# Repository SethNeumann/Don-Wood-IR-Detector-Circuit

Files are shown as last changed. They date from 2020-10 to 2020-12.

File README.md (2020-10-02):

# REPO NAME: MRCS-Don-Wood-IR-Detector-Circuit

## License: Creative Commons Attribution-NonCommercial-ShareAlike

Don Wood offerd this circuit for an optical detector based on an IR emmitter/detector pair and
it used a segment of Dr. Chubb's SMC-12 as a substrate.  This is the same circuit without the
extraneous bits and and with dedicated pads for the pot and for a limiting resistor for the
emitter.  Terminal names stay close to the originals.  This ***may*** be a cost effective or
easier option for those needing a small number of detectors.  It will work as an ambient light
detector without an emitter but you are responsible for controlling ambient light and ensuring
illumination is consistent.

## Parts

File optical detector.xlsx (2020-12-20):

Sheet: Master BOM
Qty | Value | Device | Package | Parts | Description | Vendor | V-Part | Unit | Extd | EOQ
2 | 2 | CONNECTOR-M021X02-LOCK | 1X02_LOCK | J3, J4 | PHOENIX CONNECTOR | Asian |  | 0.25
1 | 6 | CONNECTOR-M06LOCK | 1X06_LOCK | J2 | Header 6 Standard 6-pin 0.1 header" | Asian |  | 0.50
1 | 8 | CONNECTOR-M08LOCK | 1X08_LOCK | J1 | Header 8 | Asian |  | 0.70
4 | 0 | RPTH-R0 | CUT-R | R7, R9, R10, R11 | Resistor
2 | 10K | TRIM_US-RS3 | RS3 | R2, R5 | POTENTIOMETER | Banggood |  | 0.07
1 | 1N5819 | DIODEPTH | DIODE-1N4001 | D1 | Diode | Jameco |  | 0.06
2 | 4700 | RPTH04 | AXIAL-0.4-RES | R3,R4 | Resistor | Jameco |  | 0.04
4 | 470 | RPTH04 | AXIAL-0.4-RES | R1, R6, R8, R12 | Resistor | Jameco |  | 0.04
1 | DC PWR | CONNECTOR-DC-POWER-RA | DCJ0202 | CON1 | DC POWER JACK | Asian |  | 0.10
1 | LM324N | LM324N | DIL14 | U1 | OP AMP | Jameco |  | 0.25
2 | RED | LED3MM | LED3MM | LED1, LED2 |  | Asian |  | 0.01
1 |  | PCB |  |  | MRCS-Don-Woods-IR-Detector | MRCS |  | 1.67
1 | labor | pin |  |  |  |  |  | 0.20
 | Markup | 20%
 | ecommerce | 10%

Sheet: Minimal-Single
Qty | Value | Device | Package | Parts | Description | Vendor | V-Part | Unit | Extd | EOQ | leads | leads extd
 | 2 | CONNECTOR-M021X02-LOCK | 1X02_LOCK | J3, J4 | PHOENIX CONNECTOR | Asian | 0 | 0.25 | 0.00 | 100 | 2 | 0
1 | 6 | CONNECTOR-M06LOCK | 1X06_LOCK | J2 | Header 6 Standard 6-pin 0.1 header" | Asian | 0 | 0.50 | 0.50 | 100 | 6 | 6
 | 8 | CONNECTOR-M08LOCK | 1X08_LOCK | J1 | Header 8 | Asian | 0 | 0.70 | 0.00 | 100 | 8 | 0
 | 0 | RPTH-R0 | CUT-R | R7, R9, R10, R11 | Resistor |  | 0 | 0.00 | 0.00 | 100 | 2 | 0
1 | 10K | TRIM_US-RS3 | RS3 | R2, R5 | POTENTIOMETER | Banggood | 0 | 0.07 | 0.07 | 100 | 3 | 3
1 | 1N5819 | DIODEPTH | DIODE-1N4001 | D1 | Diode | Jameco | 0 | 0.06 | 0.06 | 100 | 2 | 2
1 | 4700 | RPTH04 | AXIAL-0.4-RES | R3,R4 | Resistor | Jameco | 0 | 0.04 | 0.04 | 100 | 2 | 2
 | 470 | RPTH04 | AXIAL-0.4-RES | R1, R6, R8, R12 | Resistor | Jameco | 0 | 0.04 | 0.00 | 100 | 2 | 0
 | DC PWR | CONNECTOR-DC-POWER-RA | DCJ0202 | CON1 | DC POWER JACK | Asian | 0 | 0.10 | 0.00 | 100 | 3 | 0
1 | LM324N | LM324N | DIL14 | U1 | OP AMP | Jameco | 0 | 0.25 | 0.25 | 100 |  | 0
1 | DIL14 | Socket DIL14 | LED3MM | U1S | 14 oin dip socket | Jameco |  | 0.20 | 0.20 | 100 | 14 | 14
1 | 0 | PCB | 0 | 0 | MRCS-Don-Woods-IR-Detector | MRCS | 0 | 1.67 | 1.67 | 100
 |  | Parts total |  |  |  |  |  |  | 2.79 |  |  | 27
27 |  | Labor |  |  |  |  |  | 0.20 | 5.40
 |  | Cost subtotal |  |  |  |  |  |  | 8.19
 |  | Markup |  |  |  |  |  |  | 1.64
 |  | marked up subtotal |  |  |  |  |  |  | 9.83
 |  | E-commerce |  |  |  |  |  |  | 0.98
 |  | Grand Total |  |  |  |  |  |  | 10.81
 |  | Sell |  |  |  |  |  |  | $11.00

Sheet: Dual with Emitters
Qty | Value | Device | Package | Parts | Description | Vendor | V-Part | Unit | Extd | EOQ | leads | leads extd
 | 2 | CONNECTOR-M021X02-LOCK | 1X02_LOCK | J3, J4 | PHOENIX CONNECTOR | Asian | 0 | 0.25 | 0.00 | 100 | 2 | 0
1 | 6 | CONNECTOR-M06LOCK | 1X06_LOCK | J2 | Header 6 Standard 6-pin 0.1 header" | Asian | 0 | 0.50 | 0.50 | 100 | 6 | 6
1 | 8 | CONNECTOR-M08LOCK | 1X08_LOCK | J1 | Header 8 | Asian | 0 | 0.70 | 0.70 | 100 | 8 | 8
 | 0 | RPTH-R0 | CUT-R | R7, R9, R10, R11 | Resistor |  | 0 | 0.00 | 0.00 | 100 | 2 | 0
2 | 10K | TRIM_US-RS3 | RS3 | R2, R5 | POTENTIOMETER | Banggood | 0 | 0.07 | 0.14 | 100 | 3 | 6
1 | 1N5819 | DIODEPTH | DIODE-1N4001 | D1 | Diode | Jameco | 0 | 0.06 | 0.06 | 100 | 2 | 2
2 | 4700 | RPTH04 | AXIAL-0.4-RES | R3,R4 | Resistor | Jameco | 0 | 0.04 | 0.08 | 100 | 2 | 4
2 | 470 | RPTH04 | AXIAL-0.4-RES | R1, R6, R8, R12 | Resistor | Jameco | 0 | 0.04 | 0.08 | 100 | 2 | 4
 | DC PWR | CONNECTOR-DC-POWER-RA | DCJ0202 | CON1 | DC POWER JACK | Asian | 0 | 0.10 | 0.00 | 100 | 3 | 0
1 | LM324N | LM324N | DIL14 | U1 | OP AMP | Jameco | 0 | 0.25 | 0.25 | 100 |  | 0
1 | DIL14 | Socket DIL14 | LED3MM | U1S | 14 oin dip socket | Jameco |  | 0.20 | 0.20 | 100 | 14 | 14
1 | 0 | PCB | 0 | 0 | MRCS-Don-Woods-IR-Detector | MRCS | 0 | 1.67 | 1.67 | 100
 |  | Parts total |  |  |  |  |  |  | 3.68 |  |  | 44
44 |  | Labor |  |  |  |  |  | 0.20 | 8.80
 |  | Cost subtotal |  |  |  |  |  |  | 12.48
 |  | Markup |  |  |  |  |  |  | 2.50
 |  | marked up subtotal |  |  |  |  |  |  | 14.98
 |  | E-commerce |  |  |  |  |  |  | 1.50
 |  | Grand Total |  |  |  |  |  |  | 16.47
 |  | Sell |  |  |  |  |  |  | $16.00

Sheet: Dual with Emitter & LEDs
Qty | Value | Device | Package | Parts | Description | Vendor | V-Part | Unit | Extd | EOQ | leads | leads extd
 | 2 | CONNECTOR-M021X02-LOCK | 1X02_LOCK | J3, J4 | PHOENIX CONNECTOR | Asian | 0 | 0.25 | 0.00 | 100 | 2 | 0
1 | 6 | CONNECTOR-M06LOCK | 1X06_LOCK | J2 | Header 6 Standard 6-pin 0.1 header" | Asian | 0 | 0.50 | 0.50 | 100 | 6 | 6
 | 8 | CONNECTOR-M08LOCK | 1X08_LOCK | J1 | Header 8 | Asian | 0 | 0.70 | 0.00 | 100 | 8 | 0
 | 0 | RPTH-R0 | CUT-R | R7, R9, R10, R11 | Resistor |  | 0 | 0.00 | 0.00 | 100 | 2 | 0
1 | 10K | TRIM_US-RS3 | RS3 | R2, R5 | POTENTIOMETER | Banggood | 0 | 0.07 | 0.07 | 100 | 3 | 3
1 | 1N5819 | DIODEPTH | DIODE-1N4001 | D1 | Diode | Jameco | 0 | 0.06 | 0.06 | 100 | 2 | 2
1 | 4700 | RPTH04 | AXIAL-0.4-RES | R3,R4 | Resistor | Jameco | 0 | 0.04 | 0.04 | 100 | 2 | 2
 | 470 | RPTH04 | AXIAL-0.4-RES | R1, R6, R8, R12 | Resistor | Jameco | 0 | 0.04 | 0.00 | 100 | 2 | 0
 | DC PWR | CONNECTOR-DC-POWER-RA | DCJ0202 | CON1 | DC POWER JACK | Asian | 0 | 0.10 | 0.00 | 100 | 3 | 0
1 | LM324N | LM324N | DIL14 | U1 | OP AMP | Jameco | 0 | 0.25 | 0.25 | 100 |  | 0
1 | DIL14 | Socket DIL14 | LED3MM | U1S | 14 oin dip socket | Jameco |  | 0.20 | 0.20 | 100 | 14 | 14
1 | 0 | PCB | 0 | 0 | MRCS-Don-Woods-IR-Detector | MRCS | 0 | 1.67 | 1.67 | 100
 |  | Parts total |  |  |  |  |  |  | 2.79 |  |  | 27
27 |  | Labor |  |  |  |  |  | 0.20 | 5.40
 |  | Cost subtotal |  |  |  |  |  |  | 8.19
 |  | Markup |  |  |  |  |  |  | 1.64
 |  | marked up subtotal |  |  |  |  |  |  | 9.83
 |  | E-commerce |  |  |  |  |  |  | 0.98
 |  | Grand Total |  |  |  |  |  |  | 10.81
 |  | Sell |  |  |  |  |  |  | $11.00

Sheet: Dual Tortoise Controller
Qty | Value | Device | Package | Parts | Description | Vendor | V-Part | Unit | Extd | EOQ | leads | leads extd
 | 2 | CONNECTOR-M021X02-LOCK | 1X02_LOCK | J3, J4 | PHOENIX CONNECTOR | Asian | 0 | 0.25 | 0.00 | 100 | 2 | 0
1 | 6 | CONNECTOR-M06LOCK | 1X06_LOCK | J2 | Header 6 Standard 6-pin 0.1 header" | Asian | 0 | 0.50 | 0.50 | 100 | 6 | 6
 | 8 | CONNECTOR-M08LOCK | 1X08_LOCK | J1 | Header 8 | Asian | 0 | 0.70 | 0.00 | 100 | 8 | 0
 | 0 | RPTH-R0 | CUT-R | R7, R9, R10, R11 | Resistor |  | 0 | 0.00 | 0.00 | 100 | 2 | 0
1 | 10K | TRIM_US-RS3 | RS3 | R2, R5 | POTENTIOMETER | Banggood | 0 | 0.07 | 0.07 | 100 | 3 | 3
1 | 1N5819 | DIODEPTH | DIODE-1N4001 | D1 | Diode | Jameco | 0 | 0.06 | 0.06 | 100 | 2 | 2
1 | 4700 | RPTH04 | AXIAL-0.4-RES | R3,R4 | Resistor | Jameco | 0 | 0.04 | 0.04 | 100 | 2 | 2
 | 470 | RPTH04 | AXIAL-0.4-RES | R1, R6, R8, R12 | Resistor | Jameco | 0 | 0.04 | 0.00 | 100 | 2 | 0
 | DC PWR | CONNECTOR-DC-POWER-RA | DCJ0202 | CON1 | DC POWER JACK | Asian | 0 | 0.10 | 0.00 | 100 | 3 | 0
1 | LM324N | LM324N | DIL14 | U1 | OP AMP | Jameco | 0 | 0.25 | 0.25 | 100 |  | 0
1 | DIL14 | Socket DIL14 | LED3MM | U1S | 14 oin dip socket | Jameco |  | 0.20 | 0.20 | 100 | 14 | 14
1 | 0 | PCB | 0 | 0 | MRCS-Don-Woods-IR-Detector | MRCS | 0 | 1.67 | 1.67 | 100
 |  | Parts total |  |  |  |  |  |  | 2.79 |  |  | 27
27 |  | Labor |  |  |  |  |  | 0.20 | 5.40
 |  | Cost subtotal |  |  |  |  |  |  | 8.19
 |  | Markup |  |  |  |  |  |  | 1.64
 |  | marked up subtotal |  |  |  |  |  |  | 9.83
 |  | E-commerce |  |  |  |  |  |  | 0.98
 |  | Grand Total |  |  |  |  |  |  | 10.81
 |  | Sell |  |  |  |  |  |  | $11.00

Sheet: options
barrel jack
limiting resistor
external power for leds

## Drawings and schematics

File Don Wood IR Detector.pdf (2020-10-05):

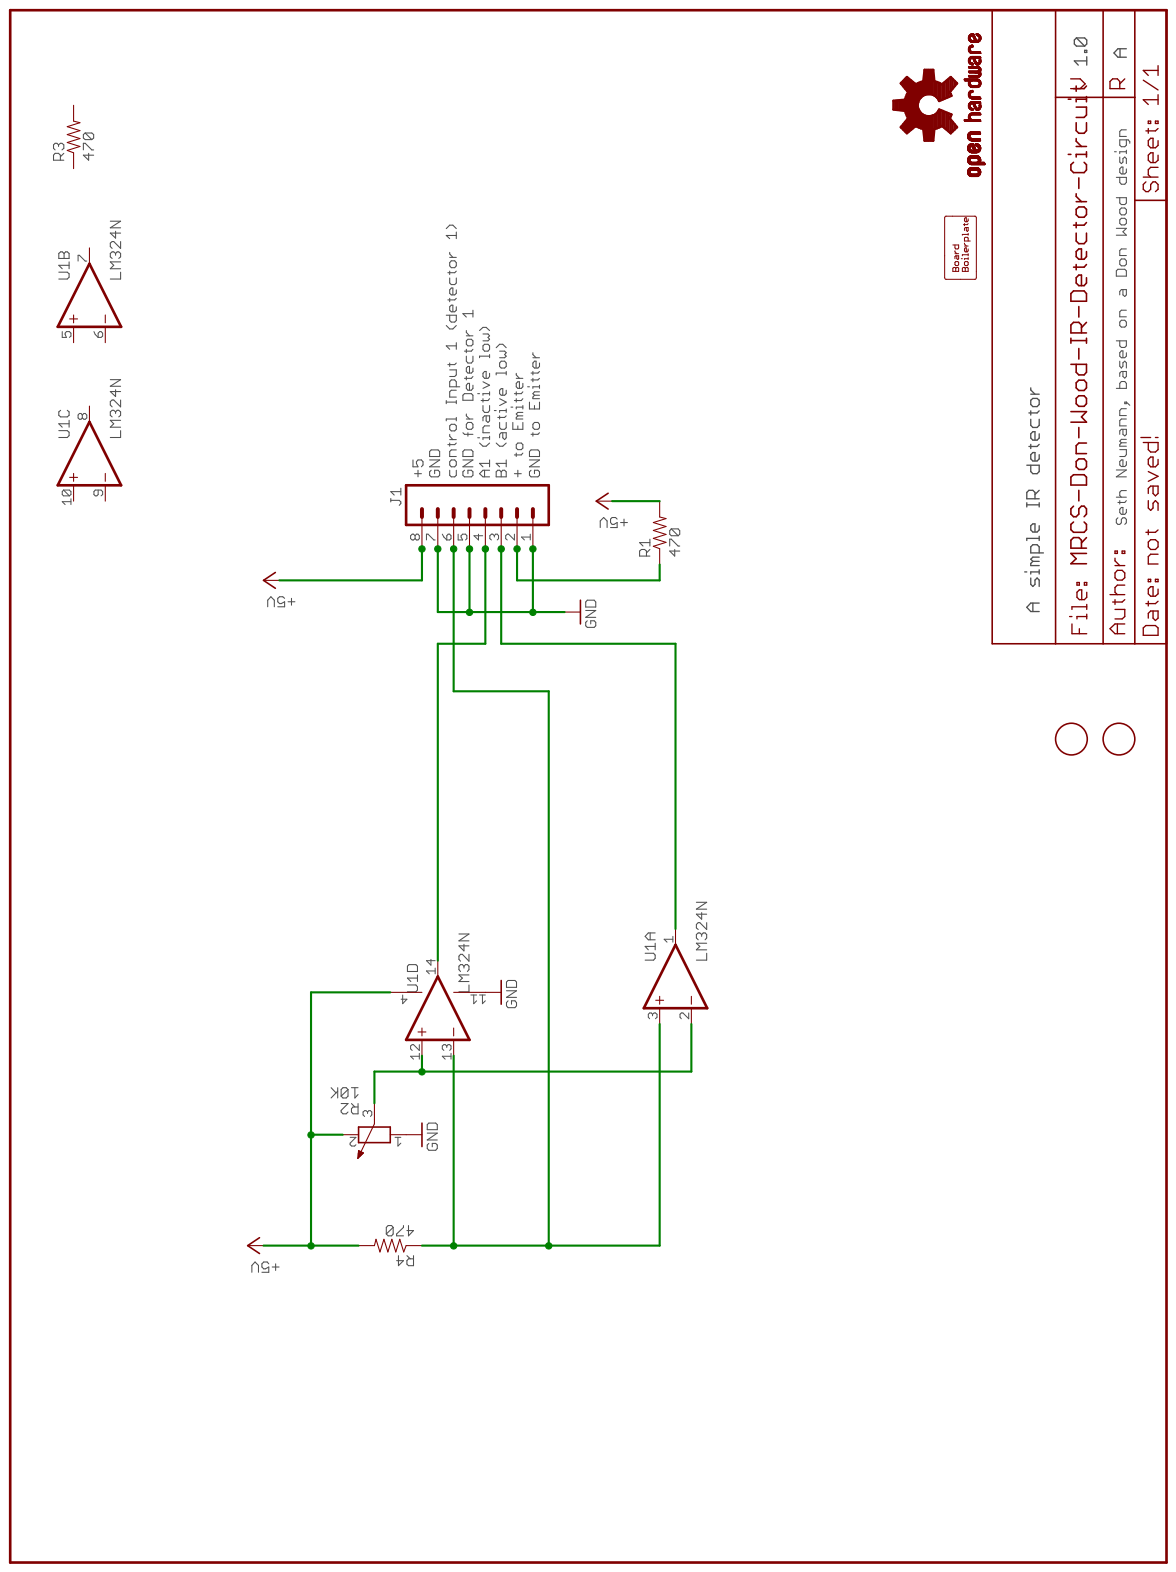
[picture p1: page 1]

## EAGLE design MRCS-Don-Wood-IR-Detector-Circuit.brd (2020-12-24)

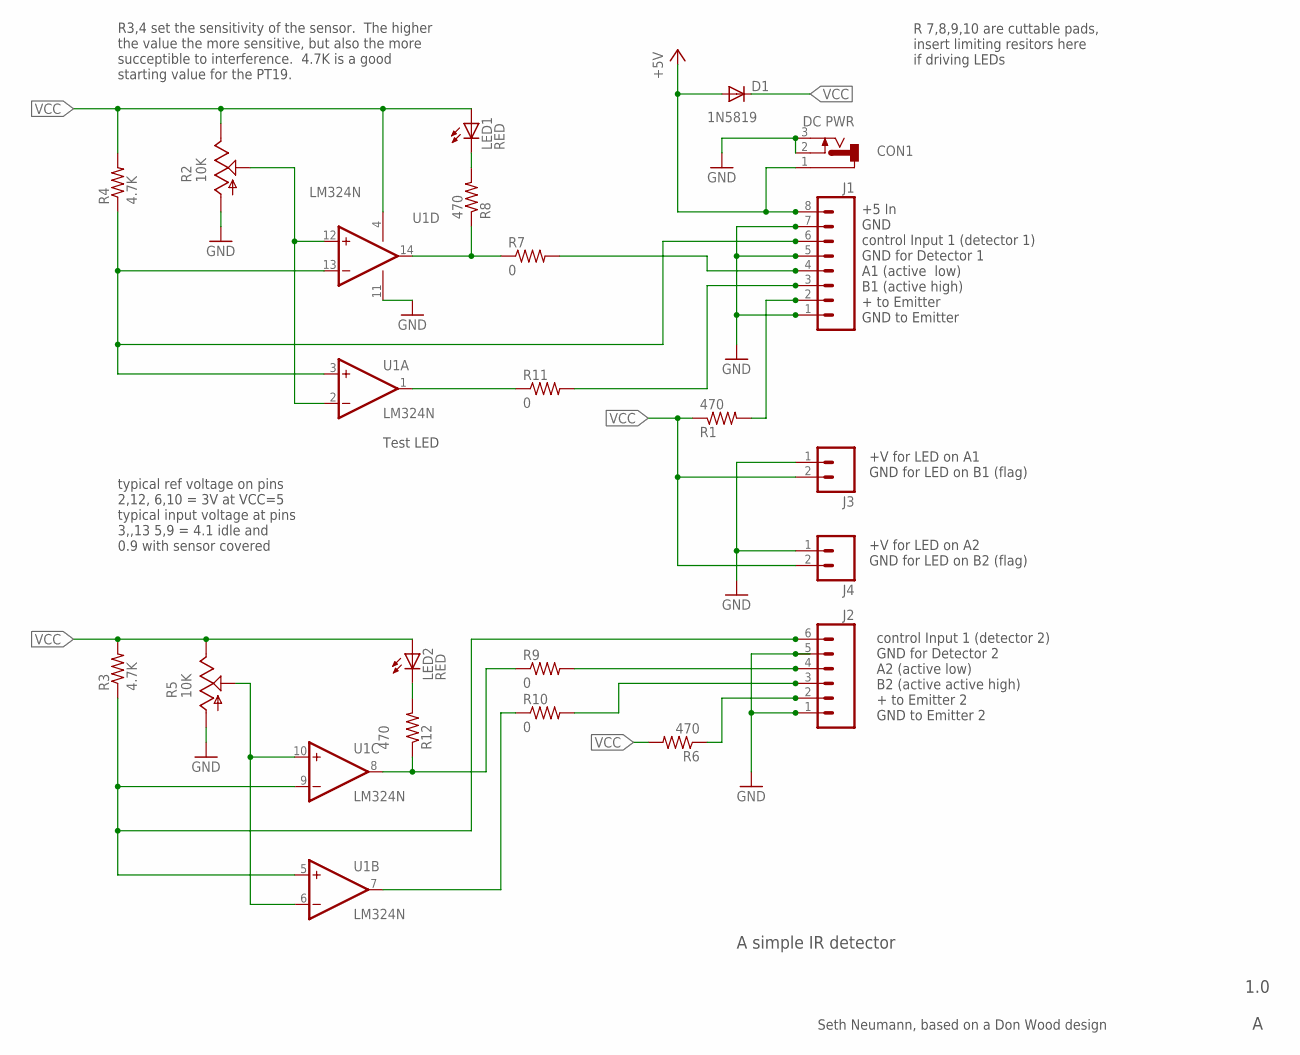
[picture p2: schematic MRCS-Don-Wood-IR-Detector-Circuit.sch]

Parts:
CON1: DC PWR; DCJ0202
D1: 1N5819; DIODE-1N4001
J1: CONNECTOR-M08LOCK; 1X08_LOCK
J2: CONNECTOR-M06LOCK; 1X06_LOCK
J3, J4: CONNECTOR-M021X02-LOCK; 1X02_LOCK
LED1, LED2: RED; LED3MM
R1, R6, R8, R12: 470; AXIAL-0.4-RES
R2, R5: 10K; RS3
R3, R4: 4.7K; AXIAL-0.4-RES
R7, R9, R10, R11: 0; CUT-R
U1: LM324N; DIL14

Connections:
+5V: CON1.1, D1.A, J1.8
A1: J1.4, R7.P1 (2)
A2: J2.4, R9.P1 (2)
B1: J1.3, R11.P1 (2)
B2: J2.3, R10.P1 (2)
GND: CON1.2, CON1.3, J1.1, J1.5, J1.7, J2.1, J2.5, J3.1 (A), J4.1 (A), R2.A, R5.A, U1.11 (V-)
IN1: J1.6, R4.P$1 (1), U1.3 (+IN), U1.13 (-IN)
IN2: J2.6, R3.P$1 (1), U1.5 (+IN), U1.9 (-IN)
unnamed: LED2.K (C), R12.P$2 (2)
unnamed: J1.2, R1.P$2 (2)
unnamed: R7.P2 (1), R8.P$1 (1), U1.14 (OUT)
unnamed: R9.P2 (1), R12.P$1 (1), U1.8 (OUT)
unnamed: R10.P2 (1), U1.7 (OUT)
unnamed: J2.2, R6.P$1 (1)
unnamed: R11.P2 (1), U1.1 (OUT)
unnamed: LED1.K (C), R8.P$2 (2)
REF1: R2.S, U1.2 (-IN), U1.12 (+IN)
REF2: R5.S, U1.6 (-IN), U1.10 (+IN)
VCC: D1.C, J3.2 (B), J4.2 (B), LED1.A, LED2.A, R1.P$1 (1), R2.E, R3.P$2 (2), R4.P$2 (2), R5.E, R6.P$2 (2), U1.4 (V+)

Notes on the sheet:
A simple IR detector
1.0
Seth Neumann, based on a Don Wood design
+5 In GND control Input 1 (detector 1) GND for Detector 1 A1 (active low) B1 (active high) + to Emitter GND to Emitter
control Input 1 (detector 2) GND for Detector 2 A2 (active low) B2 (active active high) + to Emitter 2 GND to Emitter 2
R 7,8,9,10 are cuttable pads, insert limiting resitors here if driving LEDs
+V for LED on A1 GND for LED on B1 (flag)
+V for LED on A2 GND for LED on B2 (flag)
typical ref voltage on pins 2,12, 6,10 = 3V at VCC=5 typical input voltage at pins 3,,13 5,9 = 4.1 idle and 0.9 with sensor covered
Test LED
R3,4 set the sensitivity of the sensor. The higher the value the more sensitive, but also the more succeptible to interference. 4.7K is a good starting value for the PT19.

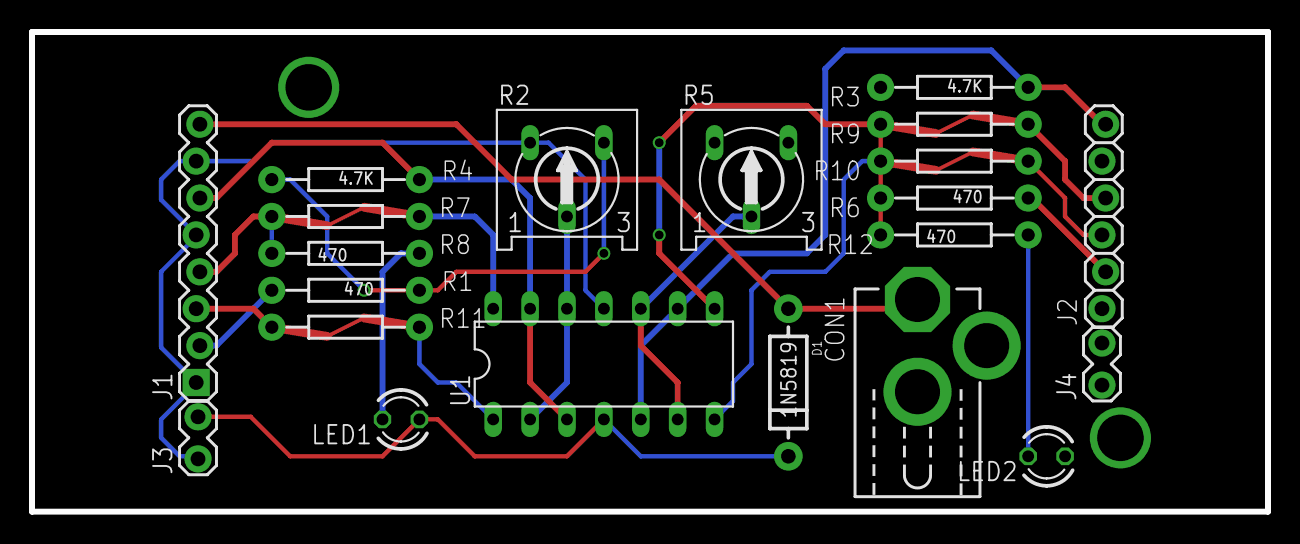
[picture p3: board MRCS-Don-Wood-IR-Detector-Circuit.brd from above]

Board: 2 copper layers, 85.1 x 33.0 mm, 24 parts (0 on the bottom side), 19 nets.

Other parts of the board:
U$1: MRCSLOGOBTM
U$2: MRCSLOGOTOP
U$3: CA-PROP65WARNING

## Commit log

2020-10-05 changes to connectors, added protection diode
    rearranged connectors so minimal system parts together, added
    protection diode
    [MRCS-Dom-Wood-IR-Detector-Circuit.brd, MRCS-Dom-Wood-IR-Detector-Circuit.sch, MRCS-Don-Wood-IR-Detector-Circuit.brd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]
2020-10-29 first board sent to JLC
    first board
    [EagleTemplate-new.brd, EagleTemplate-new.sch, MRCS-Dom-Wood-IR-Detector-Circuit.brd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]
2020-11-24 moved the status LED to show illumination present
    The LED now lights when the the illumination is present. This is to help calibrate detection when using InfraRed illumination and reflected light set ups.
    [MRCS-Don-Wood-IR-Detector-Circuit.brd, MRCS-Don-Wood-IR-Detector-Circuit.sch, optical detector.xlsx]
2020-12-20 misc work files
    should not show up
    [optical detector.xlsx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]
2020-12-24 Minor label changes, added work files to gitignore
    Changed the extra power and ground pads to "+5" and "GND" rather than LED+ and LED-. They can also be used for daisy chaining power and still can beused to power LEDs.
    [MRCS-Don-Wood-IR-Detector-Circuit.brd]

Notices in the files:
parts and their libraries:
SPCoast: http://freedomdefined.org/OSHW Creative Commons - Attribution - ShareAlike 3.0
